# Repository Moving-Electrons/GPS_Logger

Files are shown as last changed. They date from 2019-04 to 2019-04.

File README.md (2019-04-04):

# GPS Logger using CircuitPython

This is a standalone GPS logger built using Adafruit and Particle hardware. Code is in CircuitPython 4.x.

## Features

- Fully standalone GPS tracker ( not cell phone assisted).
- Location data is recorded to a micro SD card.
- Integrated screen showing basic location information.
- GPS coordinates are recorded only if the position changes by a certain predefined number of degrees. That way, we don’t end up with hundreds of recorded points for the same location if the device doesn’t move for a long period of time.
- **Battery lasts for around 70 hrs. on a single charge**. Also, it keeps working while charging.
- Integrated rechargeable battery (micro USB connector). It can be charged by pretty much any USB port or portable battery pack.
- GPS module sensitive enough to work indoors most of the time.
Bluetooth BLE ready. However, this functionality is not used on this version.

For further information on hardware components and build process, read [this article](http://www.movingelectrons.net/blog/2019/04/03/Building-a-GPS-Logger-with-CircuitPython.html) or search for it in [www.movingelectrons.net](http://www.movingelectrons.net/)

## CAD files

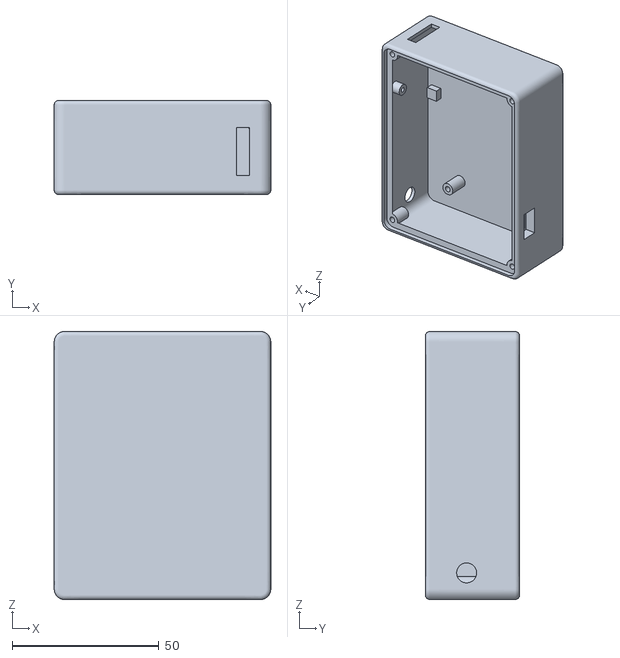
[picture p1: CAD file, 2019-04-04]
Case/gps_logger_case.stl
73.8 x 32.1 x 91.3

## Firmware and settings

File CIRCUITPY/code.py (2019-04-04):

import time
import board
import busio
import adafruit_ssd1306 
import adafruit_gps
from analogio import AnalogIn
from digitalio import DigitalInOut
import adafruit_sdcard
import storage
import os
import sys


# Constants and initial values.
oled_2ndline = oled_1stline = ''
oled_3rdline = 'Initializing...'
last_gps = (0.0, 0.0) 

# Update interval for OLED and screen messages
# IMPORTANT NOTE: Setting this interval to less than 2 seconds
# causes erratic behavior: GPS doesn't seem to be given enough time
# to update data and only a few rows are written to the SD Card. 
UPDATE_INTERVAL = 5.0 #5.0 works well
# Difference between previous and current GPS readings to record change on file.
GPS_DIFF = 0.000025 #0.00002 & 0.00003 work well

# Pin Configuration
batt = AnalogIn(board.VOLTAGE_MONITOR)

# Define RX and TX pins for the board's serial port connected to the GPS.
# These are the defaults you should use for the GPS FeatherWing.
# For other boards set RX = GPS module TX, and TX = GPS module RX pins.
RX = board.RX
TX = board.TX

# Create a serial connection for the GPS connection using default speed and
# a slightly higher timeout (GPS modules typically update once a second).
uart = busio.UART(TX, RX, baudrate=9600, timeout=3)

# for a computer, use the pyserial library for uart access
#import serial
#uart = serial.Serial("/dev/ttyUSB0", baudrate=9600, timeout=3000)

# Create a GPS module instance.
gps = adafruit_gps.GPS(uart, debug=False)

# Initialize the GPS module by changing what data it sends and at what rate.
# These are NMEA extensions for PMTK_314_SET_NMEA_OUTPUT and
# PMTK_220_SET_NMEA_UPDATERATE but you can send anything from here to adjust
# the GPS module behavior:
#   https://cdn-shop.adafruit.com/datasheets/PMTK_A11.pdf

# Turn on the basic GGA and RMC info (what you typically want)
gps.send_command(b'PMTK314,0,1,0,1,0,0,0,0,0,0,0,0,0,0,0,0,0,0,0')
# Turn on just minimum info (RMC only, location):
#gps.send_command(b'PMTK314,0,1,0,0,0,0,0,0,0,0,0,0,0,0,0,0,0,0,0')
# Turn off everything:
#gps.send_command(b'PMTK314,0,0,0,0,0,0,0,0,0,0,0,0,0,0,0,0,0,0,0')
# Tuen on everything (not all of it is parsed!)
#gps.send_command(b'PMTK314,1,1,1,1,1,1,0,0,0,0,0,0,0,0,0,0,0,0,0')

# Set update rate to once a second (1hz) which is what you typically want.
gps.send_command(b'PMTK220,1000')
# Or decrease to once every two seconds by doubling the millisecond value.
# Be sure to also increase your UART timeout above!
#gps.send_command(b'PMTK220,2000')
# You can also speed up the rate, but don't go too fast or else you can lose
# data during parsing.  This would be twice a second (2hz, 500ms delay):
#gps.send_command(b'PMTK220,500')

# creating OLED instance.
# First two parameters are the OLED screen Width and Height.
i2c = busio.I2C(board.SCL, board.SDA)
oled = adafruit_ssd1306.SSD1306_I2C(128, 32, i2c=i2c)

# Creating SD Card instance.
spi = busio.SPI(board.SCK, MOSI=board.MOSI, MISO=board.MISO)
cs = DigitalInOut(board.D5)



def batt_charge(unit='%'):
    '''
    Per Particle documentation, the voltage divider on the Particle Xenon is comprised of
    the following resistors:

    R1 = 806Kohm
    R2 = 2Mohm

    Solving for batt (voltage divider formula):
    batt = (Vpin x (R1+R2))/R2
    batt = Vpin x 1.403

    Maximum value measured at the Vpin is 3.3V, with a resolution of 16 bits (0 to 65535 units)
    provided by CircuitPython, results on 0.00005035477 per unit. Therefore:

    batt = Vpin x 1.403 x 0.00005035477

    '''

    batt_min = 3.20 # min battery level (lipo battery)
    batt_max = 3.8432 # max battery level. Lipo = 4.2v?

    volt = batt.value*1.403*0.00005035477

    # since the battery voltage doesn't go completely to "zero", a direct correlation
    # between the measured voltage and 100% cannot be done. Therefore:

    range_diff = batt_max - batt_min
    volt_diff = volt - batt_min

    percent = (volt_diff*100)/range_diff
    
    if unit == 'v': 
        return volt
    elif unit == '%':
        return percent
    

def oled_update():

    oled.fill(0)
    # Updating battery charge visualization:
    oled.text('Bat:{0:.2f}%'.format(batt_charge()), 67, 0, 1)
    oled.text(oled_1stline, 0, 0, 1)
    
    # Printing voltage on oled's 2nd line:
    #oled.text('{0:.2f} v'.format(batt.value*1.403*0.00005035477), 0, 10, 1)
    oled.text(oled_2ndline, 0, 10, 1)
    oled.text(oled_3rdline, 0, 20, 1)
    oled.show()
    return

def write_to_csv():

    # Handling optional values. Some of them may be = None.
    altitude = satellites = speed = 'Unknown'

    if gps.altitude_m is not None:
        altitude = gps.altitude_m
    if gps.satellites is not None:
        satellites = gps.satellites
    if gps.speed_knots is not None:
        speed = gps.speed_knots

    #Creates the file with header if it hasn't been created yet:
    try:
        os.stat('/sd/'+filename+'.csv')
    except OSError:
        with open ('/sd/'+filename+'.csv', 'w') as file:
            file.write('Date,Time,Latitude,Longitude,Altitude (Mts.),Speed (Knots),Fix Quality,# Satellites\r\n')

    with open ('/sd/'+filename+'.csv', 'a') as file:
        file.write('{}-{}-{},{:02}:{:02}:{:02},{:.6f},{:.6f},{},{},{},{}\r\n'.format(
            gps.timestamp_utc.tm_year,
            gps.timestamp_utc.tm_mon,
            gps.timestamp_utc.tm_mday,
            gps.timestamp_utc.tm_hour,  
            gps.timestamp_utc.tm_min,
            gps.timestamp_utc.tm_sec,
            gps.latitude,
            gps.longitude,
            altitude,
            speed,
            gps.fix_quality,
            satellites))

    return

# Mounting SD Card:
try:
    sdcard = adafruit_sdcard.SDCard(spi, cs)
except OSError:
    print('No SD card detected. Turn off, insert one and turn back on.')
    oled_1stline = ''
    oled_2ndline = 'No SD Card detected.'
    oled_3rdline = 'Off > Insert > On'
    oled_update()
    sys.exit()

vfs = storage.VfsFat(sdcard)
storage.mount(vfs, '/sd')

# Initial oled update.
oled_update()

# Main loop runs forever printing the location, etc. every second.
last_time = time.monotonic()
while True:
    # Make sure to call gps.update() every loop iteration and at least twice
    # as fast as data comes from the GPS unit (usually every second).
    # This returns a bool that's true if it parsed new data (you can ignore it
    # though if you don't care and instead look at the has_fix property).
    gps.update()


    # Updates data on oled screen, terminal and - potentially - SD Card
    # per UPDATE_INTERVAL. 
    current_time = time.monotonic()
    if current_time - last_time >= UPDATE_INTERVAL:
        last_time = current_time

        # Updates oled screen
        oled_update()
    
        
        if not gps.has_fix:
            # Try again if we don't have a fix yet.
            print('Waiting for fix...')
            print('Battery voltage: {} v.'.format(batt_charge('v')))
            oled_3rdline = 'Waiting for fix...'
            continue
        
        # We have a fix! (gps.has_fix is true)
        # Print out details about the fix like location, date, etc.
        print('=' * 40)  # Print a separator line.
        print('Fix timestamp: {}/{}/{} {:02}:{:02}:{:02}'.format(
            gps.timestamp_utc.tm_mon,   # Grab parts of the time from the
            gps.timestamp_utc.tm_mday,  # struct_time object that holds
            gps.timestamp_utc.tm_year,  # the fix time.  Note you might
            gps.timestamp_utc.tm_hour,  # not get all data like year, day,
            gps.timestamp_utc.tm_min,   # month!
            gps.timestamp_utc.tm_sec))
        print('Latitude: {} degrees'.format(gps.latitude))
        print('Longitude: {} degrees'.format(gps.longitude))
        oled_2ndline = '{},{}'.format(gps.latitude, gps.longitude)
        print('Fix quality: {}'.format(gps.fix_quality))
        oled_1stline = 'Q:{} Sat:..'.format(gps.fix_quality)
        
        # Some attributes beyond latitude, longitude and timestamp are optional
        # and might not be present.  Check if they're None before trying to use!
        if gps.satellites is not None:
            print('# satellites: {}'.format(gps.satellites))
            oled_1stline = 'Q:{} Sat:{}'.format(gps.fix_quality, gps.satellites)
       
        if gps.altitude_m is not None:
            print('Altitude: {} meters'.format(gps.altitude_m))
            oled_3rdline = 'Alt:{} mts.'.format(gps.altitude_m)
        else:
            oled_3rdline = 'Alt:...'

        if gps.track_angle_deg is not None:
            print('Speed: {} knots'.format(gps.speed_knots))
        if gps.track_angle_deg is not None:
            print('Track angle: {} degrees'.format(gps.track_angle_deg))
        if gps.horizontal_dilution is not None:
            print('Horizontal dilution: {}'.format(gps.horizontal_dilution))
        if gps.height_geoid is not None:
            print('Height geo ID: {} meters'.format(gps.height_geoid))

        print('Battery voltage: {} v.'.format(batt_charge('v')))
            
        # Writes to SD Card only if difference between the last GPS reading 
        # (latitude or longitude) and the current GPS reading is larger than 
        # a predefined value.
        current_gps = (gps.latitude, gps.longitude)
        if abs(current_gps[0] - last_gps[0]) >= GPS_DIFF or abs(current_gps[1] - last_gps[1]) >= GPS_DIFF:
            last_gps = current_gps

            filename = 'GPS_Data_{}-{}-{}'.format(
                gps.timestamp_utc.tm_year, 
                gps.timestamp_utc.tm_mon,
                gps.timestamp_utc.tm_mday)
            write_to_csv()
            
